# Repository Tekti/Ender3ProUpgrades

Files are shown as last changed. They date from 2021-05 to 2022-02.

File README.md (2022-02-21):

# Ender 3 Pro Repository

This repository contains projects related to Ender 3 Pro 3D Printers

## Anti z-wobble squares

Anti-wobble z Axis nut for Ender 3, Ender 3 pro and similiar
This design should work on any 3D printer where distance between bracket/stepper motor and middle of the screw is greater than 14mm. The nut helps with Z-wobble effect.

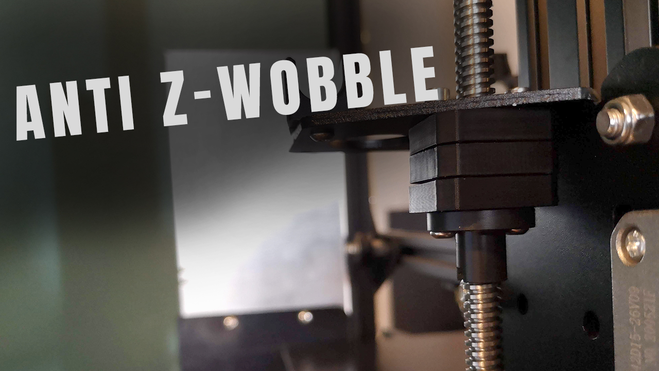
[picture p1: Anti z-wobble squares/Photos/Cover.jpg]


## Y axis tensioner

You can use this design to properly tension your belt for Y axis. The middle part, can be changed for different pulleys/bearings and also adjusted in left/right direction if the belt is binding one of the sides. The right allignment of the belt can decrease vertical artifacts on the print.

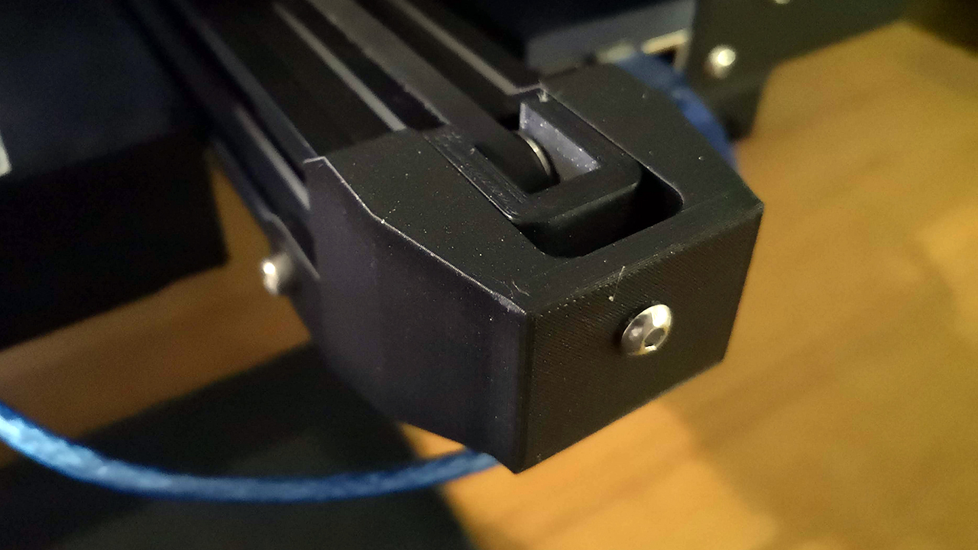
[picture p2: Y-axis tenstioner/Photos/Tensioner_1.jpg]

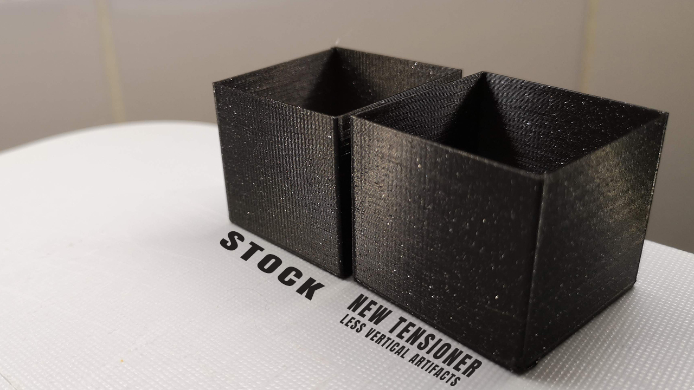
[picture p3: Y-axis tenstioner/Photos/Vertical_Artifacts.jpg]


Shield: [][cc-by-nc-sa]

This work is licensed under a
[Creative Commons Attribution-NonCommercial-ShareAlike 4.0 International License][cc-by-nc-sa].

[][cc-by-nc-sa]

[cc-by-nc-sa]: http://creativecommons.org/licenses/by-nc-sa/4.0/
[cc-by-nc-sa-image]: https://licensebuttons.net/l/by-nc-sa/4.0/88x31.png
[cc-by-nc-sa-shield]: https://img.shields.io/badge/License-CC%20BY--NC--SA%204.0-lightgrey.svg

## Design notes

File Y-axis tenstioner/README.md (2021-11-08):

# Y axis tensioner

Y axis tensioner for Ender 3 pro. You can use this design to properly tension your belt for Y axis. The middle part, can be changed for different pulleys/bearings and also adjusted in left/right direction if the belt is binding one of the sides. The right allignment of the belt can decrease vertical artifacts on the print.

### Mounting/Printing tips

-   <i>Full_Body.stl</i> print vertical, without supports
-   <i>Inside.stl</i> - print flat

Inside_+/-1mm can be used to better adjust positiong of the belt, so there is no binding. You can use this model to prepare your own version.

Additional parts:
-   M4 20mm screws - 2x

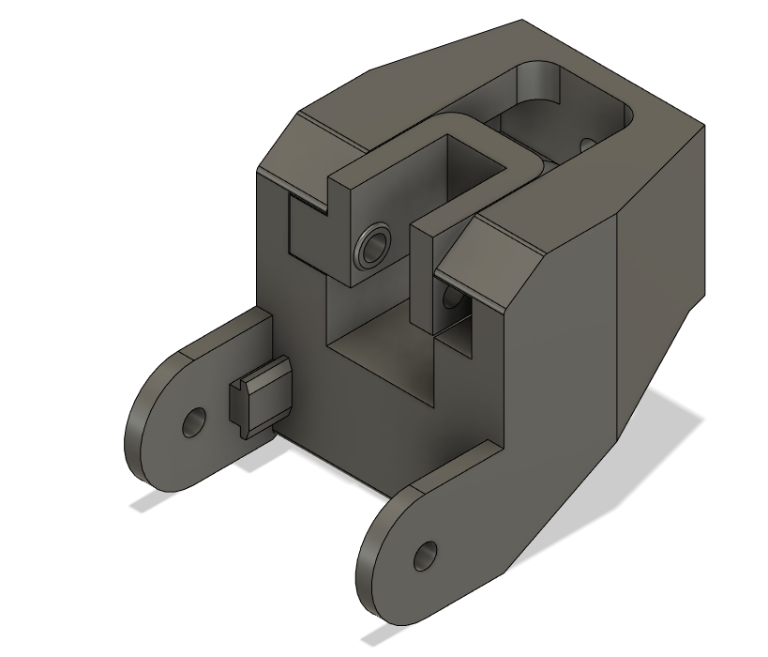
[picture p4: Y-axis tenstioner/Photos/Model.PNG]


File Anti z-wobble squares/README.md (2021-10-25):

# Anti z-wobble squares

Anti-wobble z Axis nut for Ender 3, Ender 3 pro and similiar
This design should work on any 3D printer where distance between bracket/stepper motor and middle of the screw is greater than 14mm. THe nut helps with Z-wobble effect.

Glueing of the magnets is not necessary. All magnets needs to be inserted so they attract each other.

### Direct drive mount

Description of the files:
-   <i>Square_16mm.stl</i> - used for TR8x2/4/8 nut (16 mm between mounting holes)
-   <i>Square_18mm.stl</i> - used for TR8x8 nut (original from creality, 18mm between mounting holes) and to mount device to the bracket
-   <i>Square_16mm.stl</i> - middle part

Additional parts:
-   M3 8mm screws - 2x
-   6x3mm magnets - 12x (full stabilization), 8x (enough for working)
-   4mm steel balls (I took mine from 628 bearing) - 4x

### Bowden mount

Description of the files:
-   <i>Square_16mm_Bowden_45deg.stl</i> - used for TR8x2/4/8 nut (16 mm between mounting holes)
-   <i>Square_18mm_Bowden_45deg.stl</i> - used for mounting device to the bracket
-   <i>Square_18mm_Bowden_StockNut_45deg.stl</i> - used for mounting TR8x8 nut to the device(original from creality, 18mm between mounting holes)
-   <i>Square_Middle_Bowden_45deg.stl</i> - middle part

Additional parts:
-   M3 8mm screws - 4x
-   4x4mm magnets - 12x (full stabilization), 8x (enough for working)
-   4mm steel balls (I took mine from 628 bearing) - 4x

### Example print configuration for Stock Parts with Bowden configuration
-   <i>Square_18mm_Bowden_45deg.stl</i> - Top part, should be screwed to the bottom of the bracket (steel balls aiming bottom)
-   <i>Square_18mm_Bowden_StockNut_45deg.stl</i> - Bottom Part, screwed together with the original creality z axis nut.
-   <i>Square_Middle_Bowden_45deg.stl</i> - middle part

### Metal Pins

Updated version with metal pins is added to repository. This version uses 32 additional metal pins (fi 2mm, length 8mm) on which steel balls are placed. Number of steel ball per layer was also doubled (4 per layer) to create full working plane.

Additional parts:
-   M3 8mm screws - 4x
-   6x3mm magnets - 12x
-   4mm steel balls (I took mine from 628 bearing) - 8x
-   Metal pins - Length: 8mm, fi: 2mm - 32x

__Design was made based on idea from HevOrt community and EvoMotors execution: https://www.thingiverse.com/thing:4785945__

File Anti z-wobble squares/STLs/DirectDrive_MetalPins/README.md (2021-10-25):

# Anti z-wobble squares

### Metal Pins
Here you can find updated version of anti z-wobble. (probably last version :) and only for direct drive)

This design uses 32 additional metal pins (fi 2mm, length 8mm) on which steel balls are placed. Number of steel ball per layer was also doubled (4 per layer) to create full working plane.

Additional parts:
-   M3 8mm screws - 4x
-   6x3mm magnets - 12x
-   4mm steel balls (I took mine from 628 bearing) - 8x
-   Metal pins - Length: 8mm, fi: 2mm - 32x, I have use cylindrical studs from BOSSARD: 1255622 BOSSARD Ø: 2mm; L: 8mm

Assembly:
1. For Bottom and Top part insert all metal pins, and align them correctly. You can use thin allan key to pushed them all the way into small holes on the other side.
2. For middle Part place all metal pins on one side.
3. In the middle part, place all magnets in the same direction.
4. CLose the magnets from the other side with metal pins.
5. Insert all left magnets in Top and Bottom part in the way that they will be attracted correctly with middle part. All magents needs to attract each other
6. Mount device on Ender and enjoy :)

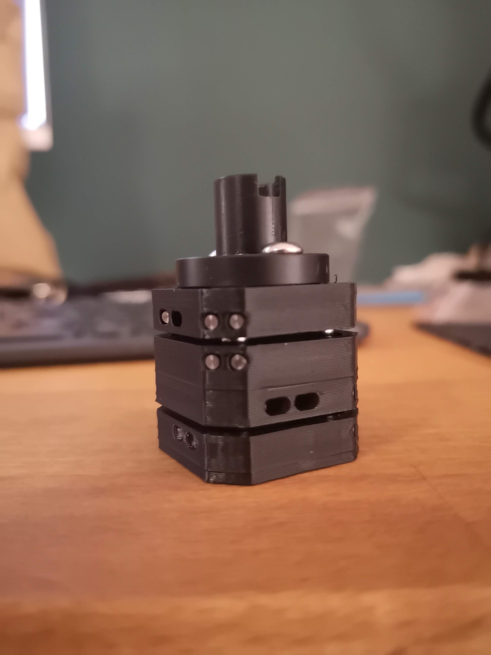
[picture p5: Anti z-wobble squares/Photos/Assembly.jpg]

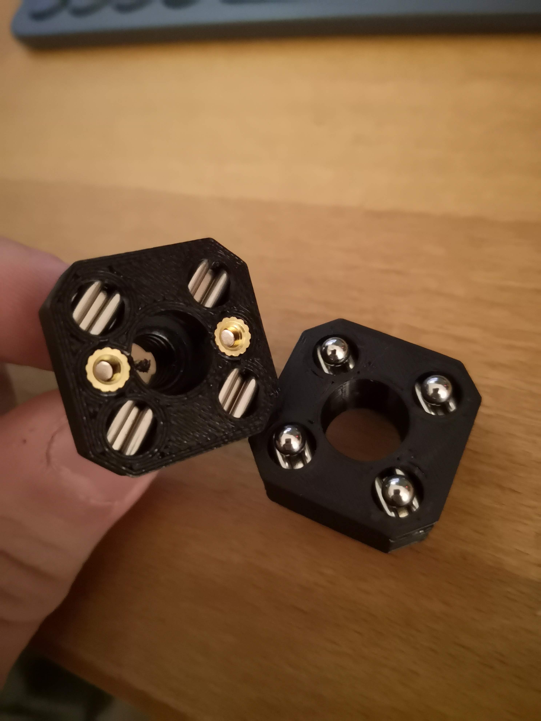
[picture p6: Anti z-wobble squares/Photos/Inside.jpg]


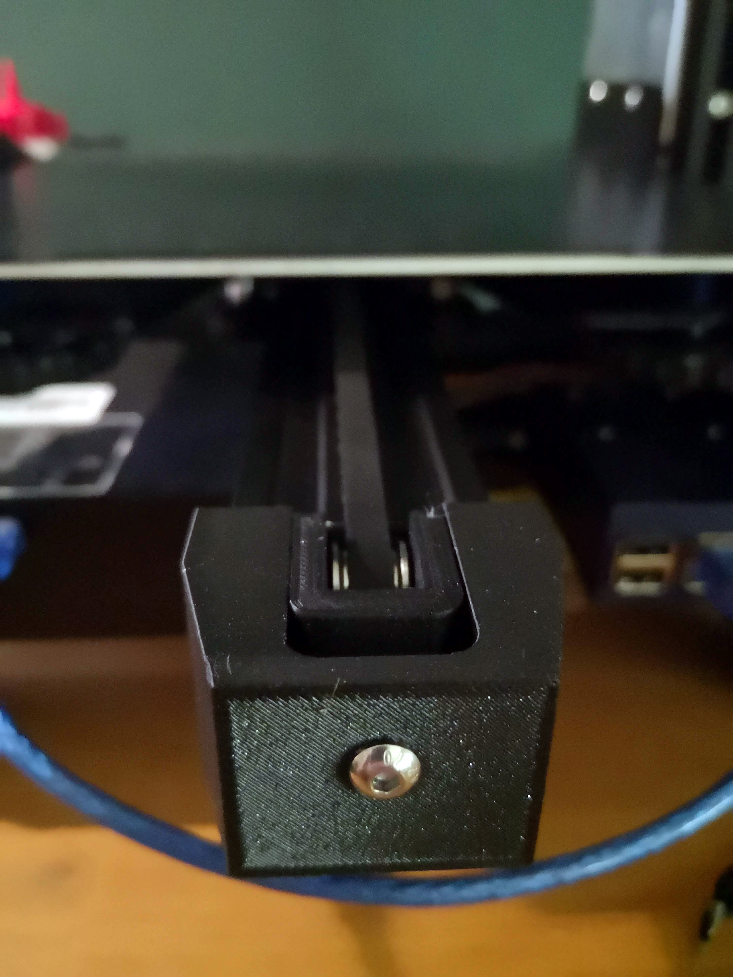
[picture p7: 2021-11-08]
Y-axis tenstioner/Photos/Tensioner_2.jpg

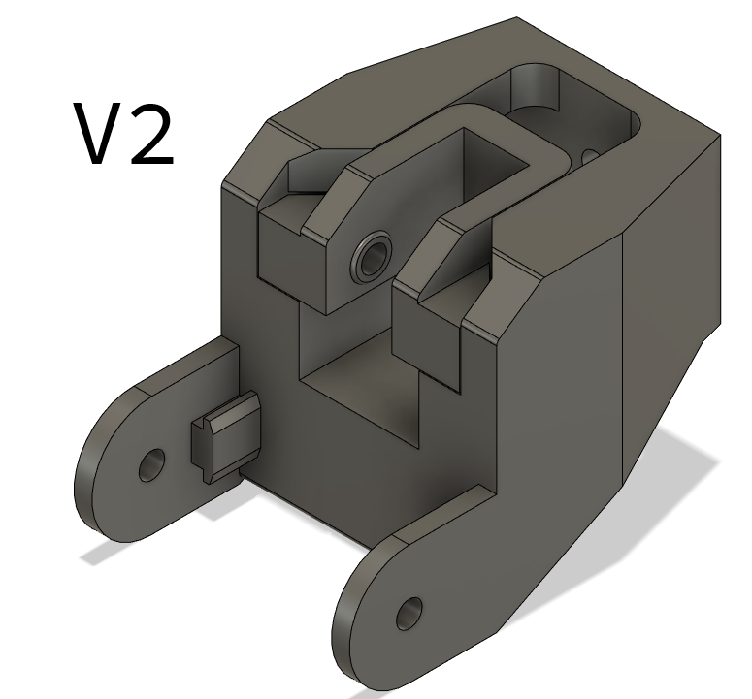
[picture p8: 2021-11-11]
Y-axis tenstioner/Photos/Model_v2.PNG

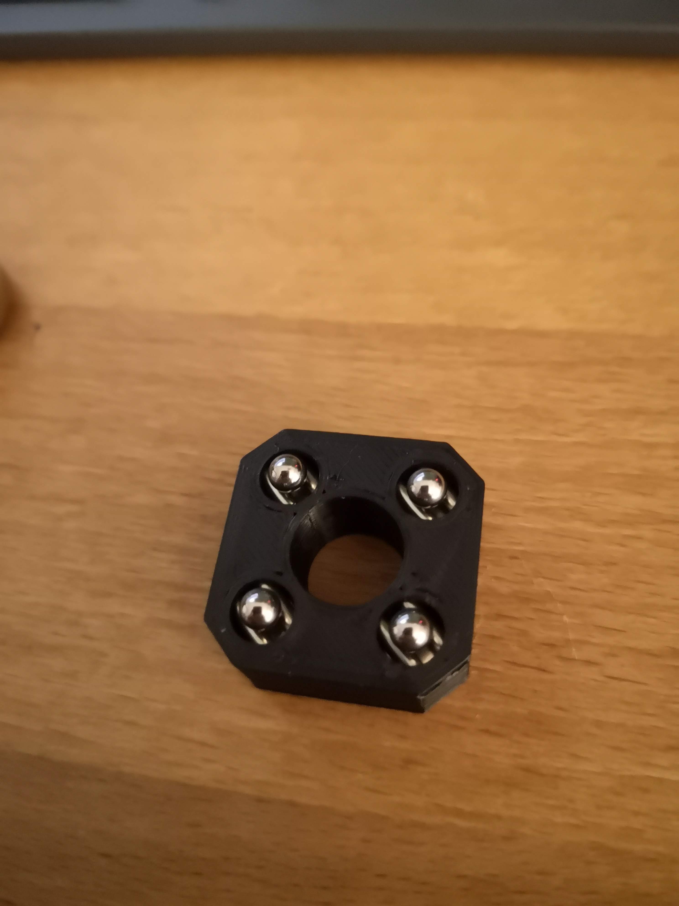
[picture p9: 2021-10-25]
Anti z-wobble squares/Photos/Bottom.jpg

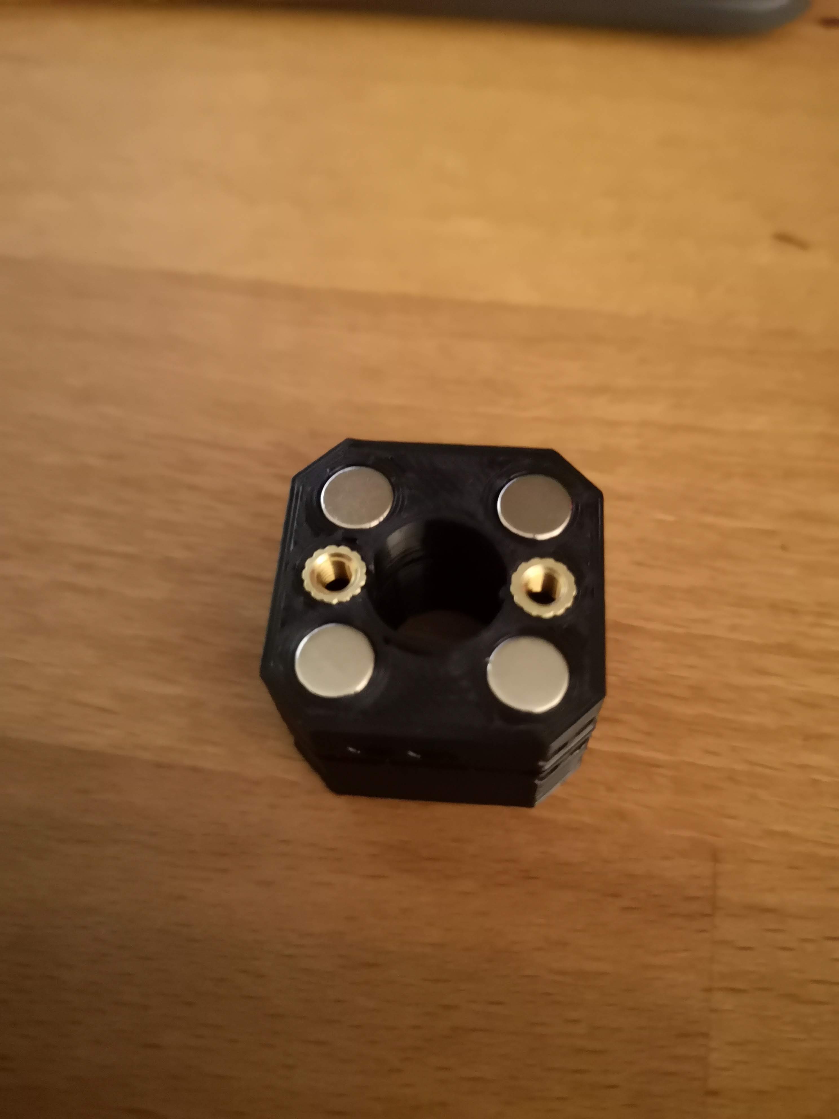
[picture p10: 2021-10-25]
Anti z-wobble squares/Photos/Top.jpg

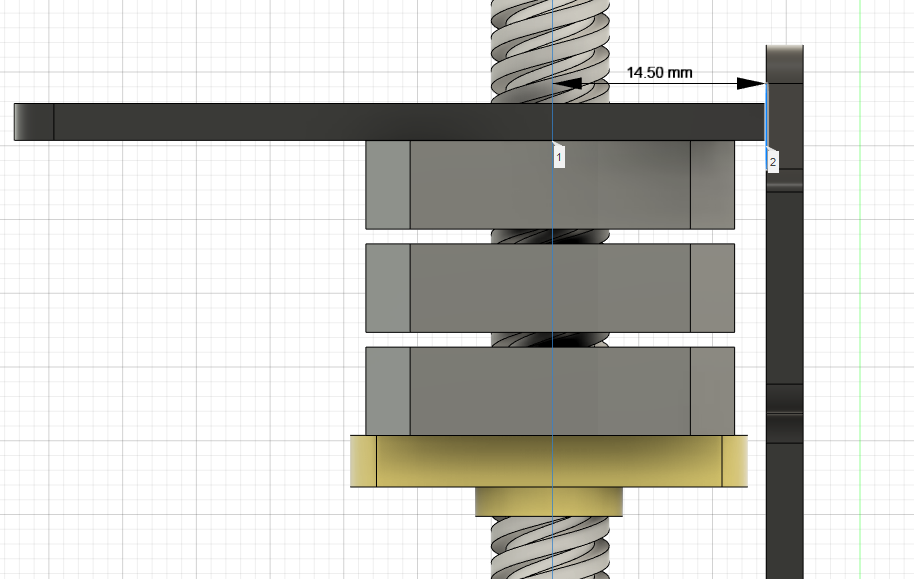
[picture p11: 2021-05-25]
Anti z-wobble squares/Photos/Distance.PNG

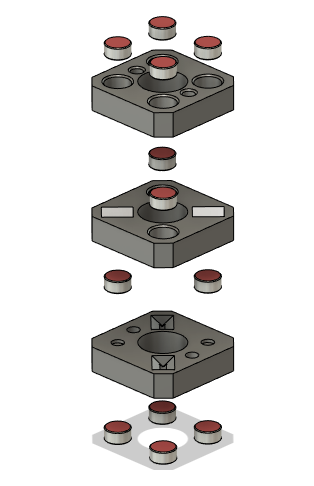
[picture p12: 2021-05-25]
Anti z-wobble squares/Photos/Exploded.PNG

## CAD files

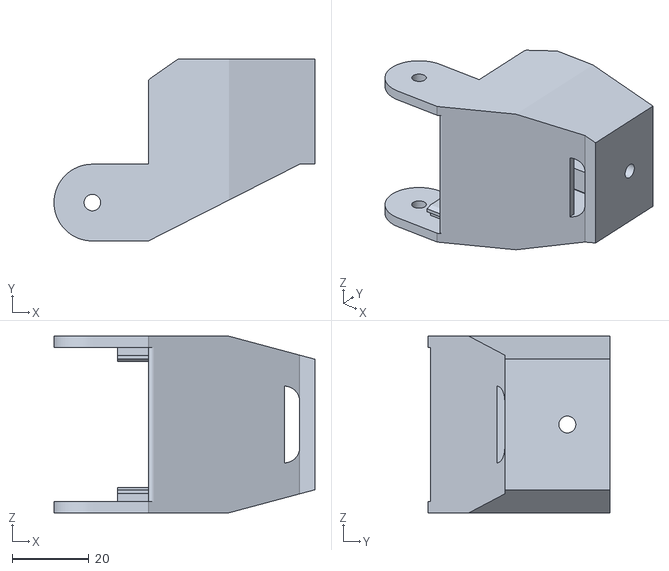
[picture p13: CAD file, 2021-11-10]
Y-axis tenstioner/Full_Body_V2.stl
68.0 x 47.4 x 46.0

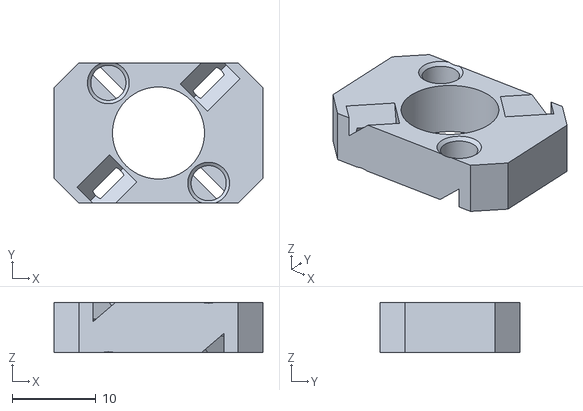
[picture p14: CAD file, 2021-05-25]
Anti z-wobble squares/STLs/Bowden/Square_Middle_Bowden_45deg.stl
25.0 x 16.8 x 6.00

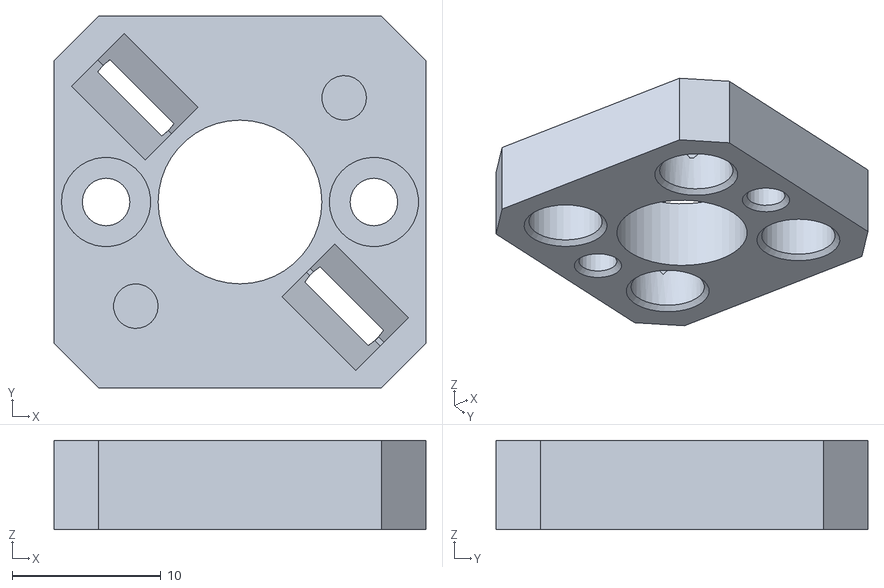
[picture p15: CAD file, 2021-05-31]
Anti z-wobble squares/STLs/DirectDrive/Square_18mm_StockNut.stl
25.0 x 25.0 x 6.00

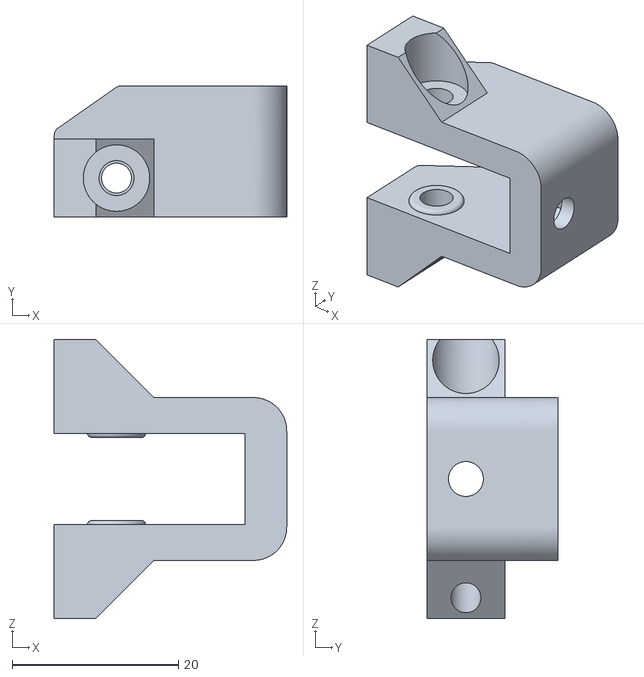
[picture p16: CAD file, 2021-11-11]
Y-axis tenstioner/Inside_V2.stl
28.0 x 15.8 x 33.6

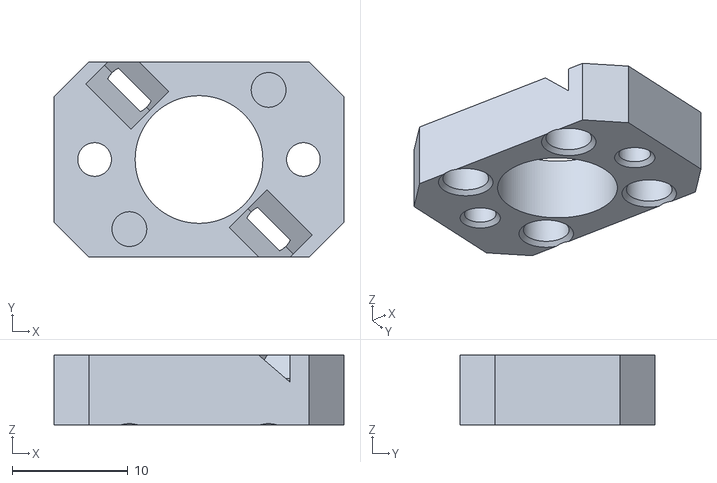
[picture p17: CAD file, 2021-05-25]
Anti z-wobble squares/STLs/Bowden/Square_18mm_Bowden_45deg.stl
25.0 x 16.8 x 6.00

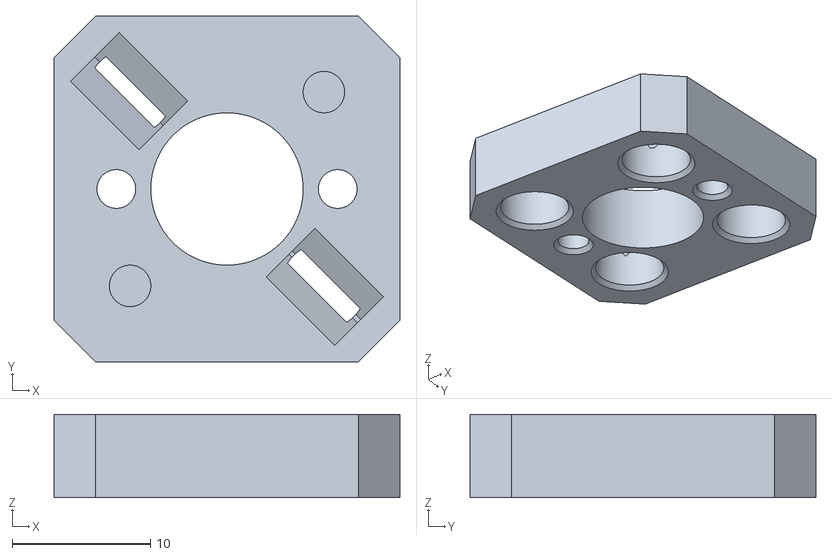
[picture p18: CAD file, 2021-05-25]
Anti z-wobble squares/STLs/DirectDrive/Square_16mm.stl
25.0 x 25.0 x 6.00

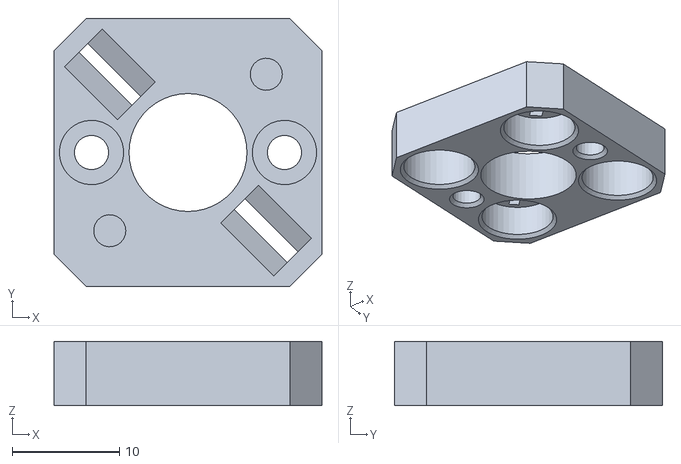
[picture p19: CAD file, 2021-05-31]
Anti z-wobble squares/STLs/DirectDrive_Magnets_8x3/Square_18mm_StockNut_8x3.stl
25.0 x 25.0 x 6.00

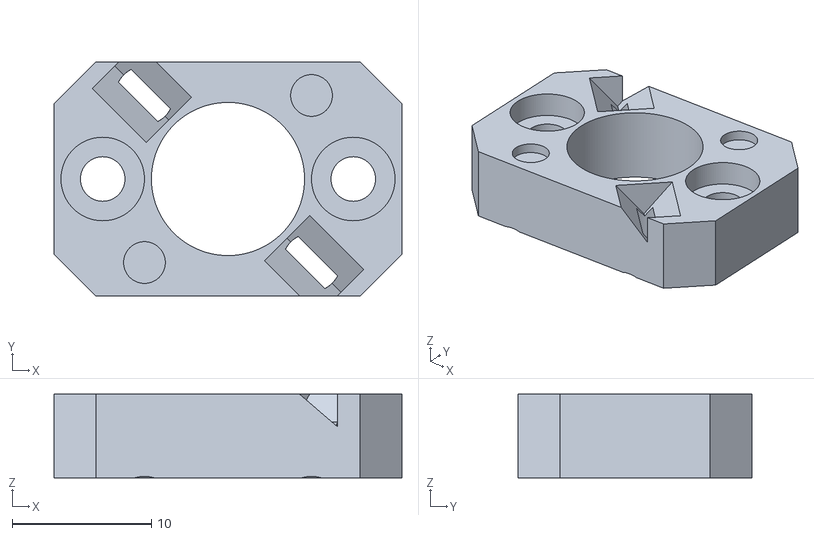
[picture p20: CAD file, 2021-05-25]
Anti z-wobble squares/STLs/Bowden/Square_18mm_Bowden_StockNut_45deg.stl
25.0 x 16.8 x 6.00

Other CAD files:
Y-axis tenstioner/Full_Body.3mf
Anti z-wobble squares/STLs/DirectDrive_Magnets_8x3/Square_18mm_8x3.stl
Anti z-wobble squares/STLs/DirectDrive_MetalPins/Heat inserts/Bottom_18mm.3mf
Anti z-wobble squares/STLs/DirectDrive_MetalPins/Top_18mm.3mf
Anti z-wobble squares/STLs/DirectDrive_MetalPins/Bottom_16mm.3mf
Anti z-wobble squares/STLs/DirectDrive_MetalPins/Heat inserts/Top_18mm.3mf
Anti z-wobble squares/STLs/DirectDrive/Square_18mm.stl
Anti z-wobble squares/STLs/DirectDrive_Magnets_8x3/Square_16mm_8x3.stl
Anti z-wobble squares/STLs/DirectDrive_MetalPins/Bottom_18mm.3mf
Anti z-wobble squares/STLs/DirectDrive_MetalPins/Heat inserts/Bottom_16mm.3mf
Anti z-wobble squares/STLs/Bowden/Square_16mm_Bowden_45deg.stl
Anti z-wobble squares/STLs/DirectDrive/Square_Middle.stl
Anti z-wobble squares/STLs/DirectDrive_Magnets_8x3/Square_Middle_8x3.stl
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

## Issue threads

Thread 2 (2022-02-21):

Metal pins

xjustbmw, 2022-02-21:
Great idea to prevent wobble.
I added dual z and its quite nasty to alin perfectly with bent z rods.

Where did you get the 8mm metal pins? Thanks

Tekti, 2022-02-21:
Metal pins which i used was from BOSSARD: 1255622 BOSSARD Ø: 2mm; L: 8mm. You can find them on tme https://www.tme.eu/en/details/b2x8_bn684/safety-pins/bossard/1255622/ or in local stores.

I have updated files for this design on the thingiverse page, it can be find here: https://www.thingiverse.com/thing:5164752

xjustbmw, 2022-02-21:
many thanks for this link

However, thinking twice about this mod on dual z axys mod
I am not sure if it will work very well since it only pushes the gantry from below and acts more like a gravitational force to come back down

IE: if one sides on dual z raises the other side higher, the magnets will not have enough force to keep the side level.

what do you think ?

Tekti, 2022-02-21:
It depends on which dual z system you are using. I am using dual z with belt connection at the top. Anti wobble is mounted on stepper drive side and it is working without any problems. With dual z on two seperate drives you should use 2 devices, mounted on each lead screw. With dual driver setup (each drive hase different stepper driver) it should be also possible to equalize the x-axis gantry.

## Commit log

2021-05-25 Add .stls and photos to Anti z-wobble
    [Square_16mm.stl, Square_16mm_Bowden_45deg.stl, Square_18mm.stl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]
2021-05-31 Add Option for magnets 8x3mm
    [Square_16mm.stl, Square_16mm_8x3.stl, Square_16mm_Bowden_45deg.stl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]
2021-10-25 Direct drive with metal pins
    [Bottom.3mf, Middle.3mf, Top.3mf]
2021-10-25 README update, .stl files added
    [Bottom.stl, Middle.stl, Top.stl]
2021-10-25 Add Heat insert and normal version
    [Bottom_16mm.3mf, Bottom_16mm.stl, Bottom_18mm.3mf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]
2021-10-25 Add assembly photos
2021-11-08 Y axis tensioner
    [Full_Body.3mf, Full_Body.stl, Inside.3mf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]
2021-11-10 New version with easier change of the inside element
    [Full_Body_V2.stl, Inside_V2.stl]
2021-11-11 Adjustments for Inside_V2.stl
    [Inside_V2.stl]

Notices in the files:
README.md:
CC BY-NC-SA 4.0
